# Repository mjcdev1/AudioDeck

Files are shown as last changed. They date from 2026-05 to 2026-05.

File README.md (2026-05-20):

# AudioDeck

## What is an AudioDeck? 
A desktop audio controller for Windows computers - allowing users to modify various sound and microphone settings on the fly without havng to stop what they are doing on their PC. 

## Compatible Component Versions for Latest Product Release
#### To ensure full compatibility, the following component versions should be used when building the latest stable version of the project:

| Component | Version |
|---|---|
| Electronics | Prototype 0.5 |
| Enclosure | Prototype 0.3 |
| Firmware | N/A |
| PC Home App | N/A |

## Important Quick Links

#### Building
| Document | Link |
|---|---|
| Pin Table | [View](docs/references/pin_table.md) |
| Key Matrix Wiring Guide | [View](docs/guides/key_matrix_wiring_guide.md) |
| Component Purchase Guide | [View](docs/guides/component_purchase_guide.md) |

#### Development
| Document | Link |
|---|---|
| Changelog | [View](docs/development/changelog.md) |
| Todo | [View](docs/development/todo.md) |

## Directory Guide
```text
/ *** The directory/ organization setup will likely change often and I will try to keep this guide updated as such
├── docs/                     
│   ├── guides/               # Setup, usage, building, troubleshooting guides 
│   ├── references/           # Datasheets, pinouts, protocols, layouts, wiring schematics (image) 
│   └── development/          # Changelog, todo, design notes
├── hardware/                 # Schematics, PCB files, wiring
│   ├── enclosure/            # All CAD files related to enclosure (case) parts
│   └── electronics/          # Wiring Schematics
|       └── PCB/              # PCB gerber files
│
├── software/            
│   ├── firmware/             # RP2040 firmware
│   └── pc-app/               # Desktop host application
│
└── README.md
```

## Plans for the AudioDeck
The AudioDeck will initially be made as a handwired version, with a PCB version eventually being released.
### Planned Features
- Control system audio volume using a slider
- Mute system audio using a key
- Mute/ unmute system microphone using a key
- Assign up to 5 customs macro keys for any purpose
- Next, Previus, Play/ Pause function keys that will control your active media session (youtube, spotify, VLC etc)
- Using the built in menu: 
  - View and modify per app audio volume of all active audio sessions (spotify, discord, chrome etc)
  - Select and update both input and output audio devices
  - Pin your favorite audio apps for quick access
  - Modify AudioDeck settings like screen brightness, encoder sensitivity and more
- Idle screen when not actively using the menu which may display things like the current time and date, and possibly even PC component status (GPU temp, CPU temp and load etc)
- A PC home app that will allow the board to communicate with your PC to allow viewing and mofications of audio sessions and devices
- Using the PC home app, you will have access to further AudioDeck preferences/ settings like:
  - Enabling/ Disabling audio apps you want to be able to see and modify on the AudioDeck
  - Setting up your custom macro keys
  - Potentionally being able to change AudioDeck screen layout/ colors/ design
  - Potentially being able to upload GIFs to be used in the idle menu
  - MORE IDEAS COMING SOON!!!

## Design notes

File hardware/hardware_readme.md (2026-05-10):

# / hardware
This directory will contain all project files pertaining to hardware, such as CAD files for the enclosure and plate, and PCB gerber files.

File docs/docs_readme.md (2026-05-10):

# / docs
This directory will contain project documentation such as guides, pin tables, component lists, and the changelog.

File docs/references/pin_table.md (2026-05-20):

# Pinout Table

> [!NOTE]
> This document provides the pinouts for the latest stable Electronics release version.
>
> Currently, it reflects the pinouts for [Electronics Prototype 0.5](/hardware/Electronics/Prototype%201.1).

> [!IMPORTANT]
> Cherry MX keyswitch pinouts are not included in this document, as they require a row/column matrix setup.
>
> Please refer to the [Key Matrix Wiring Guide](/docs/guides/key_matrix_wiring_guide.md)

> [!NOTE]
> - Unused pins from the schematic are not included in this table.
> - Unless otherwise specified, all GPIO references refer to RP2040 GPIO pins.
> - This document only covers connections from external components.
> - The RP2040 only needs to provide the shared 3V3 and GND rails used throughout the project.
> - Subscript text in the “Pin From” column shows more common pin names, while the main label matches the naming used in the project schematic.

> [!CAUTION]
> - Components purchased from vendors other than those listed in the recommended component purchase guide may have different pin layouts or orientations. As a result, some pinouts in this document may not exactly match your components.
> - For the best results and to help keep this document accurate, please use the components listed in the [Project Component Purchase Guide](/docs/guides/component_purchase_guide.md).

### EC11 Encoder A

| Pin From | Pin To |
| --- | --- |
| **S** <sub>Switch</sub> | GPIO `2` |
| **A** <sub>Out A</sub> | GPIO `3` |
| **B** <sub>Out B</sub> | GPIO `1` |
| **G** <sub>Ground</sub> | GND Rail |

### EC11 Encoder B

| Pin From | Pin To |
| --- | --- |
| **S** <sub>Switch</sub> | GPIO `27` |
| **A** <sub>Out A</sub> | GPIO `29` |
| **B** <sub>Out B</sub> | GPIO `23` |
| **G** <sub>Ground</sub> | GND Rail |

### Slider Potentiometer 10 kΩ

| Pin From | Pin To |
| --- | --- |
| **OTA** | GPIO `28` |
| **VCC** | 3V3 Rail |
| **GND** | GND Rail |

### ON-OFF-ON SPDT Toggle Switch A

| Pin From | Pin To |
| --- | --- |
| **ON_A** | GPIO `5` |
| **ON_B** | GPIO `4` |
| **GND** | GND Rail |

### ON-OFF-ON SPDT Toggle Switch B

| Pin From | Pin To |
| --- | --- |
| **ON_A** | GPIO `7` |
| **ON_B** | GPIO `6` |
| **GND** | GND Rail |

### Piezo Active Buzzer Circuit

> The longer leg of the piezo buzzer is positive, and the shorter leg is negative.

| Pin From | Through | Pin To |
| --- | --- | --- |
| 2N4401 **Base** | 1kΩ resistor | GPIO `2` |
| 2N4401 **Emitter** |  | GND Rail |
| Piezo **Negative** |  | 2N4401 **Collector** |
| Piezo **Positive** |  | 3V3 Rail |
| 1N4007 **Anode** |  | Piezo **Negative** / 2N4401 **Collector** |
| 1N4007 **Cathode** |  | 3V3 Rail |

### WS2812B ARGB LED Chain (8)

| Pin From | Through | Pin To |
| --- | --- | --- |
| LSQ1 **Base** | 1kΩ resistor | GPIO `16` |
| LSQ1 **Emitter** |  | GND Rail |
| LSQ1 **Collector** | 2.2kΩ resistor | 5V Rail |
| LSQ1 **Collector** / 2.2kΩ node | 1kΩ resistor | LSQ2 **Base** |
| LSQ2 **Emitter** |  | GND Rail |
| LSQ2 **Collector** | 2.2kΩ resistor | 5V Rail |
| LSQ2 **Collector** / 2.2kΩ node | 470Ω resistor | LED 1 **DIN** |
| LED 1 **DOUT** |  | LED 2 **DIN** |
| LED 2 **DOUT** |  | LED 3 **DIN** |
| LED 3 **DOUT** |  | LED 4 **DIN** |
| LED 4 **DOUT** |  | LED 5 **DIN** |
| LED 5 **DOUT** |  | LED 6 **DIN** |
| LED 6 **DOUT** |  | LED 7 **DIN** |
| LED 7 **DOUT** |  | LED 8 **DIN** |
| All LED **VDD** pins |  | 5V Rail |
| All LED **GND** pins |  | GND Rail |

### ILI9341 2.4" Display

| Pin From | Pin To |
| --- | --- |
| **LED** | 3V3 Rail |
| **SCK** | GPIO `26` |
| **SDI** <sub>MOSI</sub> | GPIO `22` |
| **DC** | GPIO `21` |
| **RESET** | GPIO `20` |
| **CS** | GPIO `19` |
| **GND** | GND Rail |
| **VCC** | 3V3 Rail |

### Power Filtering / Decoupling

| Pin From | Through | Pin To |
| --- | --- | --- |
| 3V3 Rail | 0.1 µF ceramic capacitor | GND Rail |
| 3V3 Rail | 4.7 µF ceramic capacitor | GND Rail |
| ILI9341 VCC | 0.1 µF ceramic capacitor | ILI9341 GND |
| R3 / 5V rail node | 0.1 µF ceramic capacitor | GND |
| R5 / 5V rail node | 0.1 µF ceramic capacitor | GND |
| LED1 VDD / 5V rail node | 0.1 µF ceramic capacitor | GND |

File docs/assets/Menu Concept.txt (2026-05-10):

Idle Screen
+------------------------------+
| 12:45 PM                     |
| Tue, Apr 28                  |
|                              |
| PC Status: Connected         |
|                              |
|                              |
+------------------------------+

Main Menu
+------------------------------+
| Main Menu                    |
|                              |
| > App Volumes                |
|   System Audio               |
|   Audio Output               |
|   Microphone Input           |
|   Settings                   |
+------------------------------+

App Volumes
+------------------------------+
| App Volumes                  |
|                              |
| > Discord   [########--] 74% |
|   Spotify   [#####-----] 50% |
|   CS2.exe   [##########]100% |
|   Chrome    [###-------] 25% |
|                              |
+------------------------------+

App Control (Spotify)
+------------------------------+
| Spotify                      |
|                              |
| Volume: 50%                  |
| [#####-----]                 |
|                              |
| Pinned: No                   |
|                              |
+------------------------------+

System Audio
+------------------------------+
| System Audio                 |
|                              |
| Volume: 100%                 |
| [##########]                 |
|                              |
| Mic: MUTED                   |
|                              |
+------------------------------+

Audio Output
+------------------------------+
| Audio Output                 |
|                              |
| > Headphones                 |
|   Speakers                   |
|                              |
|                              |
|                              |
+------------------------------+

Microphone Input
+------------------------------+
| Microphone Input             |
|                              |
| > External Mic               |
|   Built-in Mic               |
|                              |
|                              |
|                              |
+------------------------------+

Settings
+------------------------------+
| Settings                     |
|                              |
| > Brightness                 |
|   Screen Timeout             |
|   Knob Sensitivity           |
|   Reset Favorites            |
|                              |
+------------------------------+

Controls
Encoder A (Rotate)   - Navigate menus  
Encoder A (Press)    - Select/ Confirm  
Encoder A (Hold)     - Go Back  

Encoder B (Rotate)   - Adjust per-app volume  
Encoder B (Press)    - Toggle app mute  

Slider               - Master volume (always active)  

Next                 - Next track  
Previous             - Previous track  
Play/ Pause          - Toggle play/pause 

System Mute          - Mute all system audio  
Mic Mute             - Mute microphone  

M1–M5                - User defined macros

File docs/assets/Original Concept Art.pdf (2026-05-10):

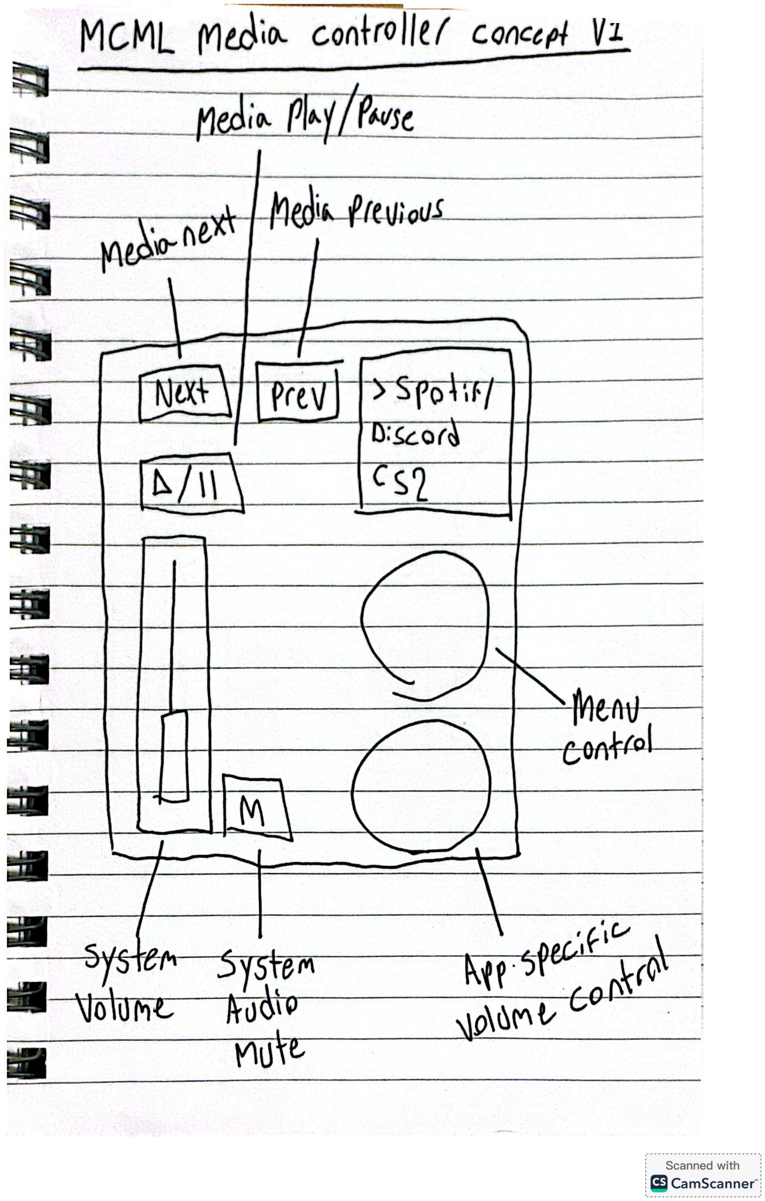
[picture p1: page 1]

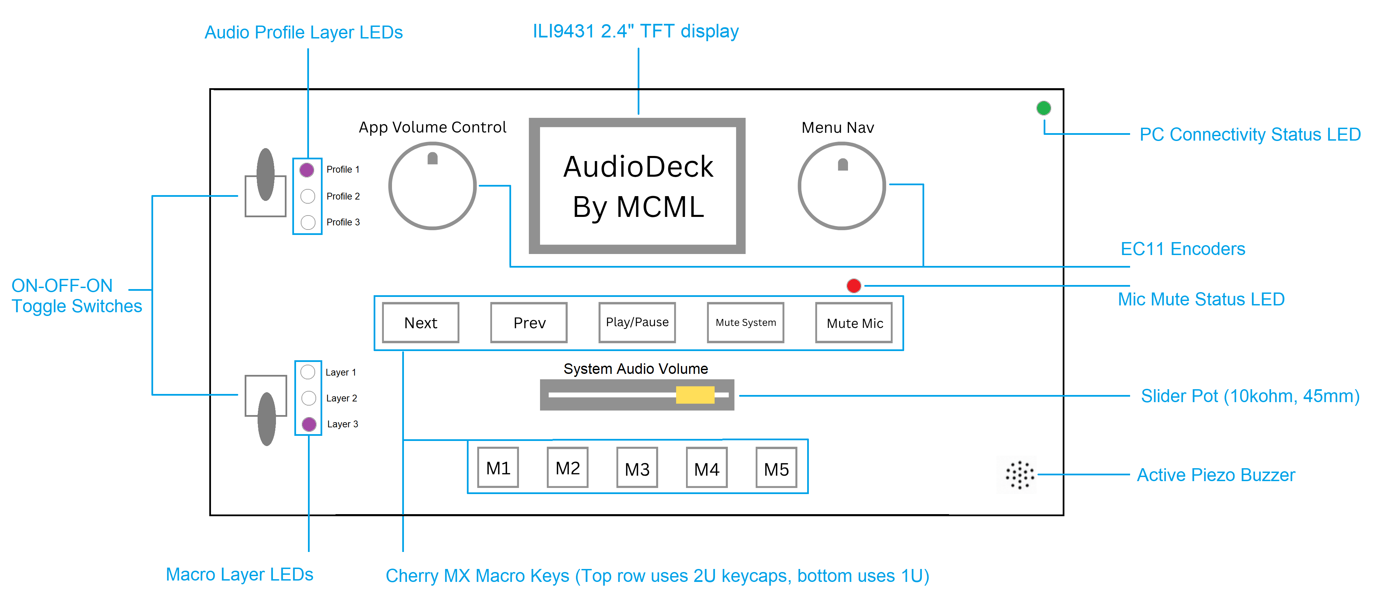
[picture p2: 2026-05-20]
docs/assets/Layout Concept of Prototype 1.4 with Labels.png

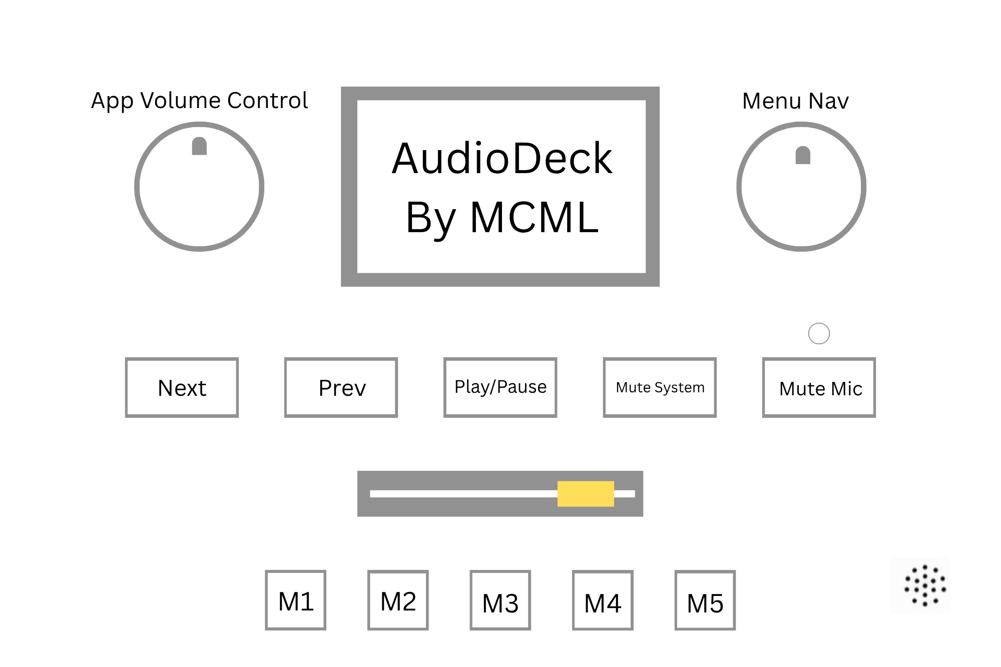
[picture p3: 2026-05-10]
docs/assets/Layout Version 1.png

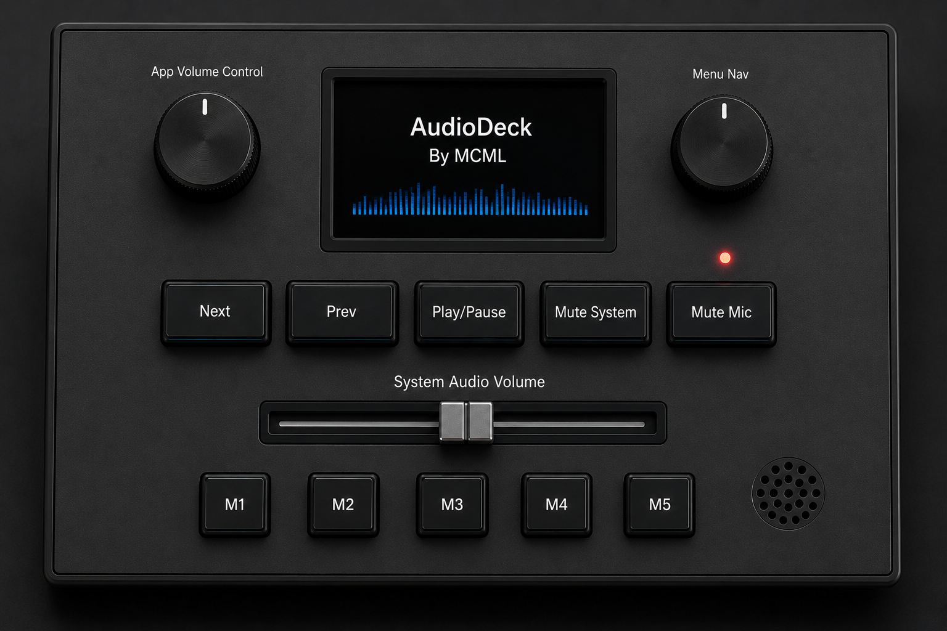
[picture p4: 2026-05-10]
docs/assets/Layout Version 1 render.png

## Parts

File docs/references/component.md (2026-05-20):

# Components

### Reference sheet showing all electronic components used in the latest stable release, along with purchase links and component history across hardware revisions.

> [!NOTE]
> This document acts as a reference sheet for all electronic components used in the latest stable hardware release, along with links to the parts used during development.
>
> It also includes the history of component additions, removals, and replacements across each hardware prototype revision.
>
> Currently, this document reflects the components used in [Electronics Prototype 0.3](/hardware/Electronics/Prototype%201.5).

> [!TIP]
> Components where the **Link** column is marked as `Any` are considered generic enough that they can typically be purchased from any vendor without causing compatibility issues.

---

# Components List

## Main Components

| Component | Quantity | Link |
| --- | --- | --- |
| EC11 Encoder | 2 | TBA |
| Cherry MX Switch | 10 | Any |
| 3-Pin ON-OFF-ON Toggle Switch | 2 | TBA |
| Generic RP2040 Pico | 1 | TBA |
| 2.4" ILI9341 TFT Display | 1 | TBA |
| 5mm WS2812B ARGB LED (Through-Hole) | 8 | TBA |
| Active Piezo Buzzer | 1 | TBA |
| 10kΩ Linear Slider Potentiometer (45mm) | 1 | TBA |

## Support Components

| Component | Quantity | Link |
| --- | --- | --- |
| 1N4148 Diode | 10 | Any |
| 470Ω Resistor | 1 | Any |
| 1kΩ Resistor | 3 | Any |
| 2.2kΩ Resistor | 2 | Any |
| 0.1uF Ceramic Capacitor | 5 | Any |
| 4.7uF Ceramic Capacitor | 1 | Any |
| 1N4007 Diode | 1 | Any |
| 2N4401 Transistor | 3 | Any |

---

# Components History

<details>
<summary><strong>Prototype 0.5</strong></summary>

#### Main Components

- Added
  - `[+]` 3× 5mm WS2812B 4-Pin ARGB LEDs (Through-Hole)
  - `[+]` 1x 3-Pin ON-OFF-ON Toggle Switch

#### Support Components

###### No additions or removals in this revision.

</details>

<details>
<summary><strong>Prototype 0.4</strong></summary>

#### Main Components

- Removed
  - `[-]` 4× 5mm CC 4-Pin Full-Color RGB LEDs (Through-Hole)

- Added
  - `[+]` 5× 5mm WS2812B 4-Pin ARGB LEDs (Through-Hole)

#### Support Components

- Removed
  - `[-]` 5× 470Ω Resistors

- Added
  - `[+]` 2× 2N4401 Transistors
  - `[+]` 2× 1kΩ Resistors
  - `[+]` 2× 2.2kΩ Resistors
  - `[+]` 3× 0.1uF Ceramic Capacitors

</details>

<details>
<summary><strong>Prototype 0.3</strong></summary>
  
#### Main Components

###### No additions or removals in this revision.

#### Support Components

###### No additions or removals in this revision.

</details>

<details>
<summary><strong>Prototype 0.2</strong></summary>

#### Main Components

- Removed
  - `[-]` 1× 5mm Red LED (Through-Hole)

- Added
  - `[+]` 4× 5mm CC 4-Pin Full-Color RGB LEDs (Through-Hole)
  - `[+]` 1× 3-Pin ON-OFF-ON Toggle Switch

#### Support Components

- Added
  - `[+]` 5× 470Ω Resistors
  - `[+]` 1× 1kΩ Resistor
  - `[+]` 1× 1N4007 Diode
  - `[+]` 1× 2N4401 Transistor
  - `[+]` 2× 0.1uF Ceramic Capacitors
  - `[+]` 1× 4.7uF Ceramic Capacitor

</details>

<details>
<summary><strong>Prototype 0.1</strong></summary>

#### Main Components

- Added
  - `[+]` 1× Generic RP2040 Pico
  - `[+]` 2× EC11 Encoders
  - `[+]` 1× 10kΩ Linear Slider Potentiometer (45mm)
  - `[+]` 1× 5mm Red LED (Through-Hole)
  - `[+]` 1× 2.4" ILI9341 TFT Display
  - `[+]` 10× Cherry MX Switches
  - `[+]` 1× Active Piezo Buzzer

#### Support Components

- Added
  - `[+]` 10× 1N4148 Diodes
  - `[+]` 1× 470Ω Resistor

</details>

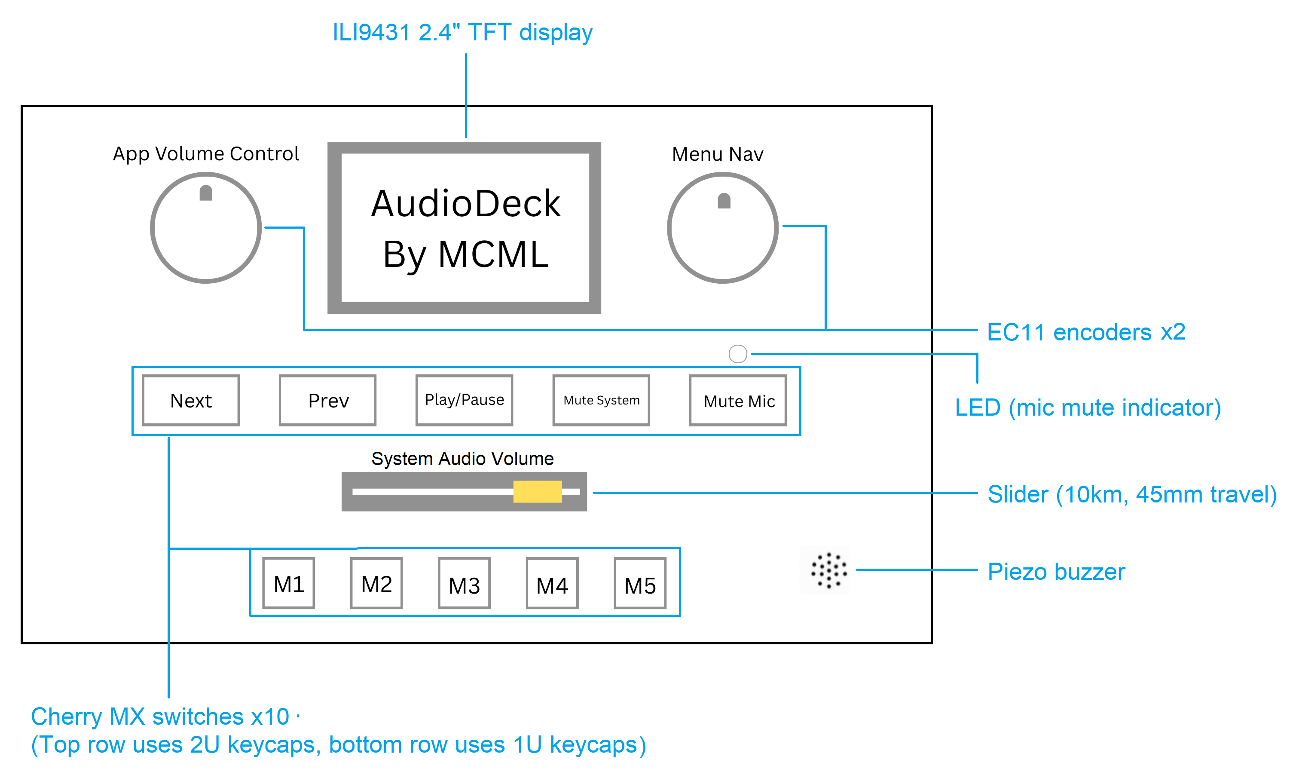
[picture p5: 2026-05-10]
docs/assets/Layout Version 1 with Labeled Components-.png

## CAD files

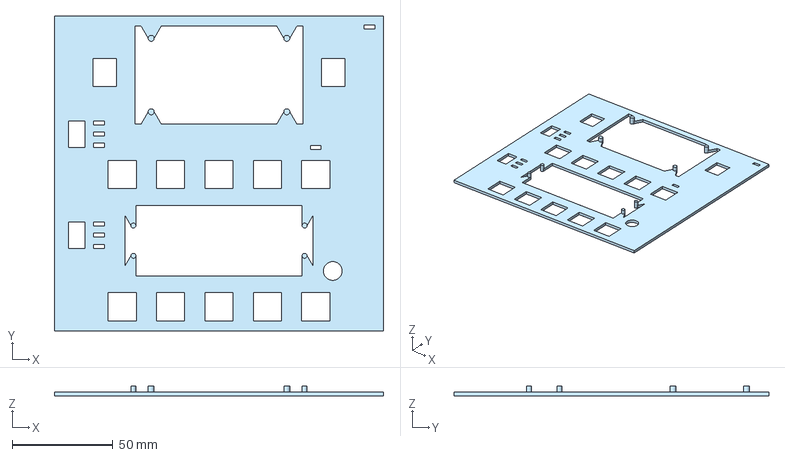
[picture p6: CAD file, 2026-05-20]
hardware/Enclosure/Prototype 0.3/Plate/Prototyping Plate 0.3.step
163.3 x 156.3 x 5.00 mm

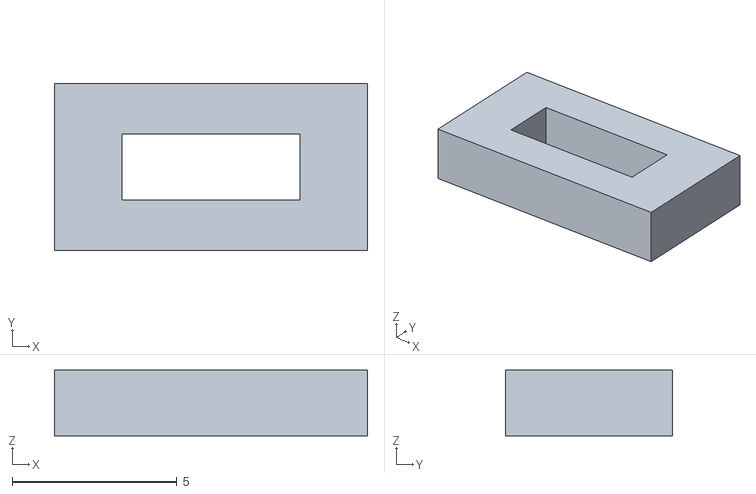
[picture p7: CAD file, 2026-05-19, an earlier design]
hardware/Enclosure/Prototype 0.2/Plate/Slot fit tests/Full-Color LED fit test.stl
9.51 x 5.07 x 2.00

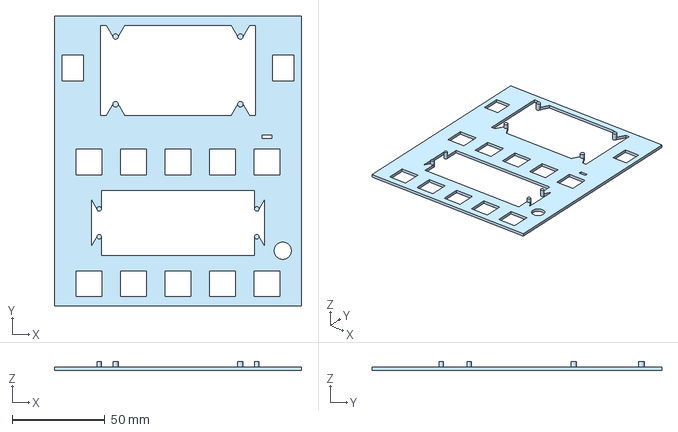
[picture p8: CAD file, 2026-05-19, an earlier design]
hardware/Enclosure/Prototype 0.1/Plate/Prototyping plate.step
133.3 x 156.3 x 5.00 mm

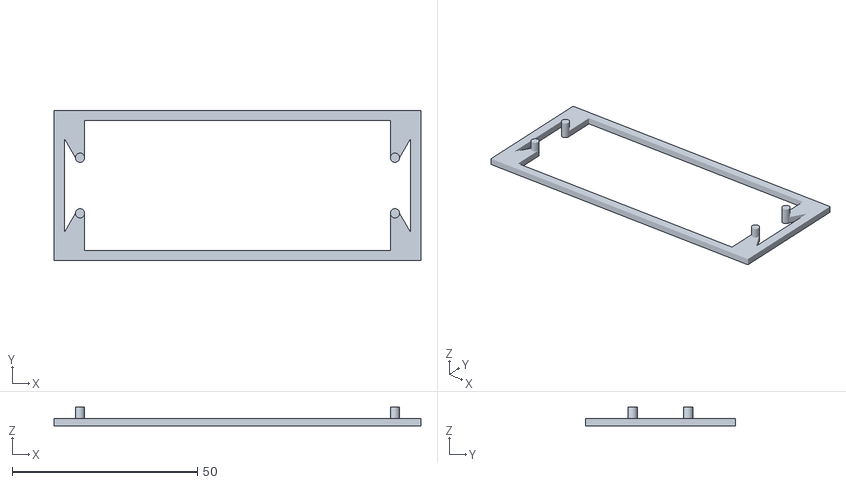
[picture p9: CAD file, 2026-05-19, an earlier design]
hardware/Enclosure/Prototype 0.1/Plate/Slot fit tests/Slider fit test.stl
99.1 x 40.5 x 5.00

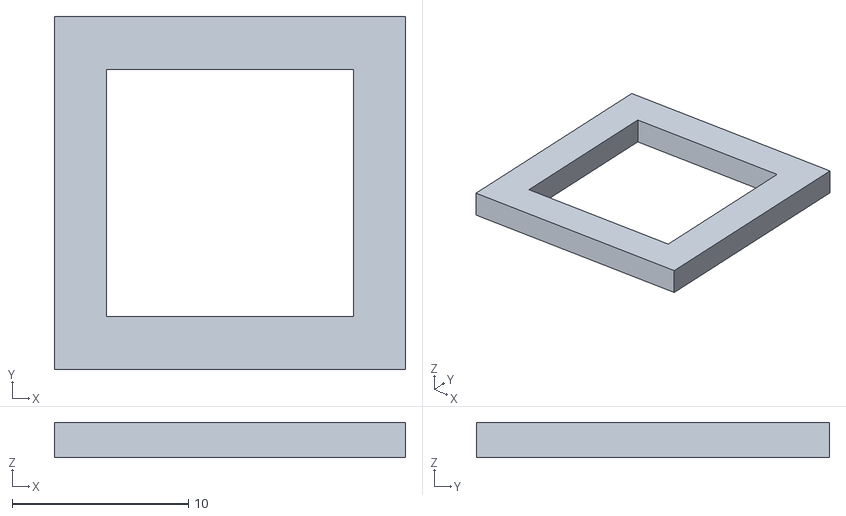
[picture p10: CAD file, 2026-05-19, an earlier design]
hardware/Enclosure/Prototype 0.1/Plate/Slot fit tests/Cherry MX fit test.stl
19.9 x 20.0 x 2.00

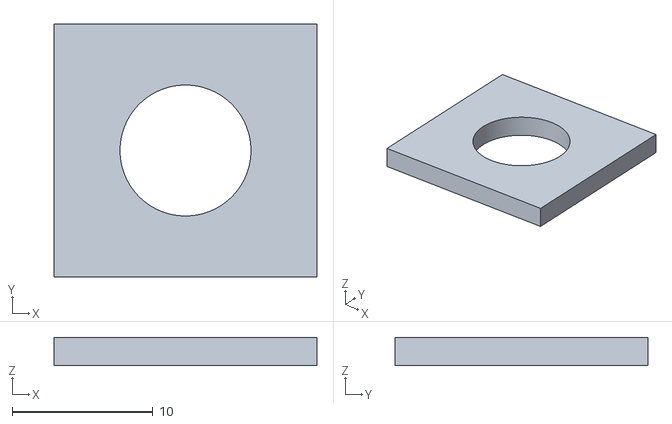
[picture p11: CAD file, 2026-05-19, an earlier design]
hardware/Enclosure/Prototype 0.2/Plate/Slot fit tests/Piezo Buzzer fit test.stl
18.7 x 18.0 x 2.00

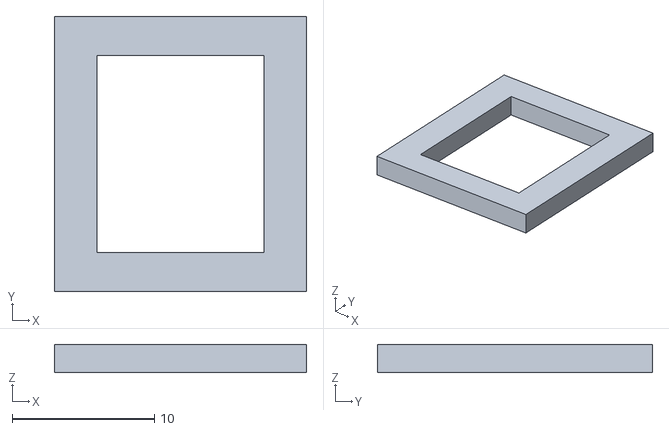
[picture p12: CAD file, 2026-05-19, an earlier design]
hardware/Enclosure/Prototype 0.1/Plate/Slot fit tests/EC11 fit test.stl
17.7 x 19.3 x 2.00

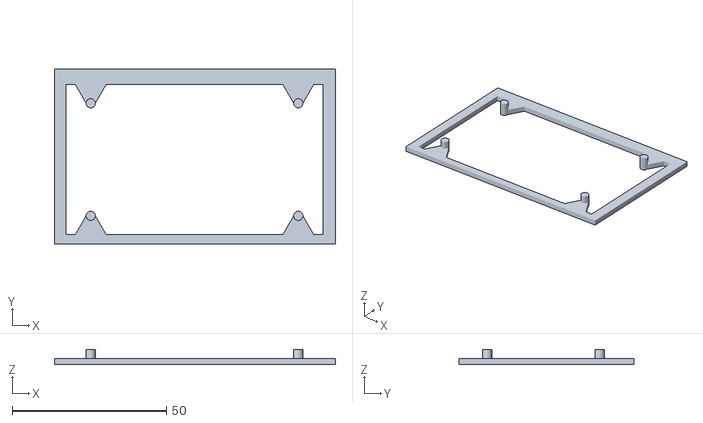
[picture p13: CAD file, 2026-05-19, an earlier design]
hardware/Enclosure/Prototype 0.1/Plate/Slot fit tests/ILI9341 fit test.stl
91.1 x 56.6 x 5.00

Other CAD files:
hardware/Enclosure/Prototype 0.2/Plate/Prototyping Plate 0.2.step
hardware/Enclosure/Prototype 0.1/Plate/Prototyping plate.stl
hardware/Enclosure/Prototype 0.2/Plate/Prototyping Plate 0.2.stl
hardware/Enclosure/Prototype 0.3/Plate/Prototyping Plate 0.3.stl

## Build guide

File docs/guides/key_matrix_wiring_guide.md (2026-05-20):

# Key Matrix Wiring Guide

### Matrix Configuration

This project uses a **COL2ROW** key matrix configuration for the 10 Cherry MX key switches. 

In this arrangement:
- Columns connect directly to one side of each keyswitch
- The opposite switch pin connects to the anode of the diode
- The cathode of the diode connects to the row wire
  > Note: You can determine the cathode side of a 1N4148 by the end with the black stripe

You will repeat this process for each key to form the columns and rows. 

This table shows the connections for a single key: 
| Connection | Connects To |
|---|---|
| Column Wire | Switch Pin 1 |
| Switch Pin 2 | Diode Anode |
| Diode Cathode (black stripe) | Row Wire |

### Matrix current path:

```text
Column → Switch → Diode → Row
```

### Diode Orientation

| Diode Side | Connection |
|---|---|
| Anode | Switch Pin 2 |
| Cathode | Row Wire |

> [!WARNING]
> All matrix diodes **have** to face the exact same direction
>
> Reversed diode orientation may prevent proper matrix scanning or cause ghosting issues.

---

### Matrix GPIO Pinout

With the rows and columns formed, you can directly connect them (from anywhere on the wires) to the below GPIO pins: 

| Matrix Reference | GPIO Pin |
|---|---|
| COL1 | GPIO `11` |
| COL2 | GPIO `12` |
| COL3 | GPIO `13` |
| COL4 | GPIO `14` |
| COL5 | GPIO `15` |
| ROW1 | GPIO `10` |
| ROW2 | GPIO `9` |

---

> [!NOTE]
> Cherry MX switches are not polarized, therefore you can orient the switch any way you want as long as one pin follows the columns and the other follows the rows.

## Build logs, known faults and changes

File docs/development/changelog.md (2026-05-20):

<!--
COLLAPSIBLE CHANGELOG ENTRY TEMPLATE

<details>
<summary><strong>Prototype X.X — YYYY/MM/DD</strong></summary>

- Main change
  - Sub change
  - Sub change

- Another main change
  - Sub change

</details>

-->

# Changelog!

## 🔌 HARDWARE — Prototype 0.3

### ENCLOSURE

<details>
<summary><strong>Prototype 0.3</strong></summary>

#### 2026/05/19
- Added four additional LED slots
- Added slot for a second ON-OFF-ON SPDT toggle

</details>

<details>
<summary><strong>Prototype 0.2</strong></summary>

#### 2026/05/12
- Added three additional LED slots
- Added slot for an ON-OFF-ON SPDT toggle switch
- Tested fitment of all component cutouts using 3D printed test pieces
  - Adjusted EC11 cutouts for improved fitment

</details>

<details>
<summary><strong>Prototype 0.1</strong></summary>

#### 2026/05/10
- Designed initial prototyping plate with mounts and cutouts for all planned components
  - Created individual fit-test cutouts before printing the full plate

</details>

### ELECTRONICS

<details>
<summary><strong>Prototype 0.5 </strong></summary>

#### 2026/05/19

- Added three more WS2812B ARGB LEDs
  - Intended to indicate the current macro layer
- Added another 3-pin ON-OFF-ON toggle switch (Referred to as Toggle Switch B)
  - Will allow the user to switch between three macro layers
- Rearranged some pin placements, specifically affecting the key matrix, EC11-A and Toggle Switch A.
- Updated pinout reference to reflect changes

</details>

<details>
<summary><strong>Prototype 0.4 </strong></summary>

#### 2026/05/18

- Added 5V rail net from VOUT on RP2040
- Created and added a custom schematic symbol for WS2812B ARGB LEDs (through-hole, individual)
- Replaced all common cathode 4-pin RGB LEDs with WS2812B ARGB LEDs
- Added support circuitry for addressable LED communication
- Added double-transistor level shifter for 3.3V to 5V data conversion
- Added additional (5th) ARGB LED

</details>

<details>
<summary><strong>Prototype 0.3 </strong></summary>

#### 2026/05/13
- Completely rewired the 10-key matrix
- Converted matrix wiring to a COL2ROW configuration
- Corrected previous matrix routing issues to ensure proper electrical functionality

</details>

<details>
<summary><strong>Prototype 0.2</strong></summary>

#### 2026/05/12

- Changed MIC MUTE LED to a 4-pin common cathode RGB LED
- Added three additional RGB LEDs
  - Intended to indicate active macro layers or custom audio profiles
- Created and added a custom schematic symbol for a 3-pin ON-OFF-ON SPDT toggle switch
  - Intended for macro layer and audio profile selection
- Rearranged several GPIO assignments
  - Primarily affecting EC11 (B) and the piezo buzzer
- Redesigned the piezo buzzer circuit
  - Added transistor driver and flyback diode protection
- Added additional decoupling capacitors throughout the circuit

</details>

<details>
<summary><strong>Prototype 0.1</strong></summary>

#### 2026/05/10

- Designed the initial wiring schematic
- Created custom symbols for unsupported components
  - RP2040
  - ILI9341
- Added shared VCC and GND nets
- Connected all primary external components to the RP2040

</details>

## 💻 SOFTWARE — v0.0.0

### FIRMWARE — v0.0.0

No changes yet.

### PC APP — v0.0.0

No changes yet.

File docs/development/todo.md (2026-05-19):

# Todo!

## Todo in Hardware...
  - [ ] Build simple prototype on breadboard
    - [ ] Design prototyping plate
  - [ ] Change schematic to use 4 pin (4 color) LED instead of single color

## Todo in Software...

## Todo in Documentation/ Assets/ Organization...
  - [X] Reorganize directories per updated organization design... 
    - [X] Move /assets into /docs [ ]
    - [X] Create /docs/guides, /docs/references, and /docs/development 
    - [X] Move changelog.md, changelog_rules.md and todo.md into /docs/development [ ]
    - [X] Create /software and move /firmware and /pc-app into it [ ]

 - [X] Create pinout table
 - [ ] Create key switch matrix wiring guide

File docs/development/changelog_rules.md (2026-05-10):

# Changelog Rules and Conventions

### Semantic Versioning
- Semantic versioning uses the format:
  - vMAJOR.MINOR.PATCH
  - Example:
    - v1.4.2
- Semantic version updates should use the following format:
  - vX.X.X ([CHANGE TYPE]) — [DATE YYYY/MM/DD]
  - Example:
    - v1.3.4 (PATCH) — 2026/04/19
- MAJOR versions represent large redesigns, rewrites, or breaking changes.
- MINOR versions represent new features, systems, or meaningful improvements.
- PATCH versions represent smaller fixes, tweaks, refinements, or corrections.

### Hardware Revision Versioning
- Hardware revision versioning uses the format:
  - Rev A1, Rev A2, Rev B1, Rev B2, etc.
- Hardware revision updates should use the following format:
  - Rev A2 ([CHANGE TYPE]) — [DATE YYYY/MM/DD]
  - Example:
    - Rev B3 (MINOR) — 2026/04/19
- Increment the revision number for smaller revisions or improvements.
- Increment the revision letter for major redesigns or new hardware generations.

### Project Versioning
- Project versions use the format:
  - PROJECT — VX
  - Example:
    - PROJECT — V3
- Project version updates should use the following format:
  - PROJECT — VX — [DATE YYYY/MM/DD]
  - Example:
    - PROJECT — V3 — 2026/04/19
- Project versions represent the overall milestone and progression state of the project as a whole.
- A new Project version should only be created when the project has reached a meaningful new milestone, stage, or release state.

### Project Structure
- The Project is made up of the following categories:
  - Hardware
    - Enclosure
    - Electronics
  - Software
    - Firmware
    - PC Companion App
  - Documentation and Assets

### Hardware Revision Progression
- Hardware uses Hardware Revision Versioning.
- Hardware revisions are determined by the combined progression of the Enclosure and PCB categories.
- A Hardware revision should only increment once both Enclosure and PCB have reached or exceeded the intended revision milestone.
  - Example:
    - Hardware should only reach Rev A2 once both Enclosure and PCB have reached at least Rev A2 or greater.

### Software Version Progression
- Software uses Semantic Versioning.
- Software versions are determined by the combined progression of Firmware and the PC Companion App.
- A Software version should only increment once both Firmware and the PC Companion App have reached or exceeded the intended semantic version milestone.
  - Example:
    - Software should only reach v0.3.0 once both Firmware and the PC Companion App have reached at least v0.3.0 or greater.

### Documentation and Assets Versioning
- Documentation and Assets use Hardware Revision Versioning.
- Documentation and Assets revisions should reflect the overall progression of documentation, organization, and asset-related changes within the category.

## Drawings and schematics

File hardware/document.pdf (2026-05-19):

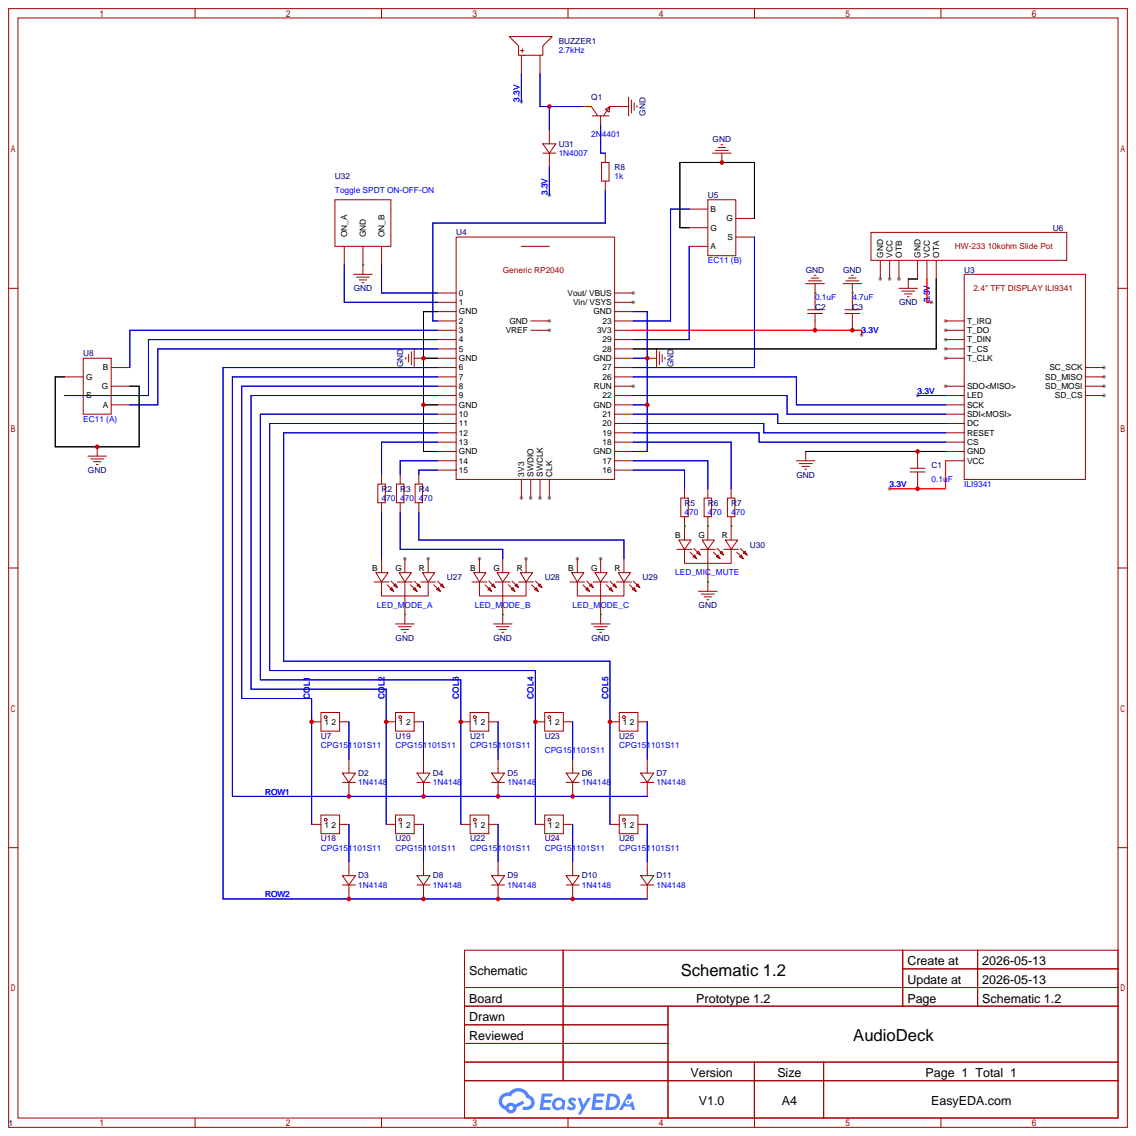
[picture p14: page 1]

Toggle SPDT ON-OFF-ON

Schematic | Schematic 1.2 | Create at | 2026-05-13

Update at | 2026-05-13

Board | Prototype 1.2 | Page | Schematic 1.2
Drawn | | AudioDeck
Reviewed

Version | Size | Page 1 Total 1
V1.0 | A4 | EasyEDA.com

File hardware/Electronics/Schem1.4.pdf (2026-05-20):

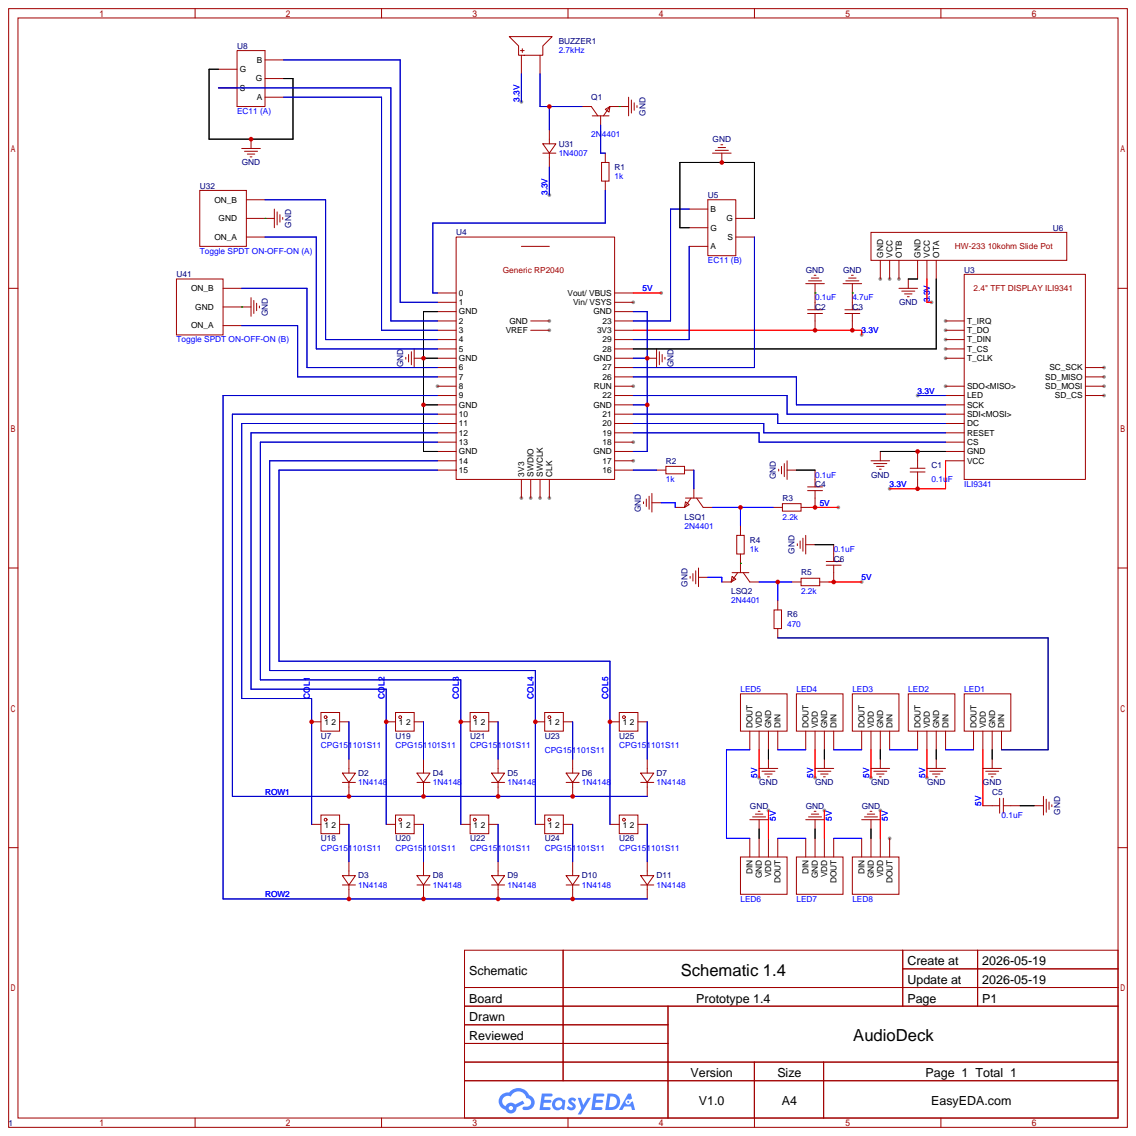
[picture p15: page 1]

Schematic | Schematic 1.4 | Create at | 2026-05-19

Update at | 2026-05-19

Board | Prototype 1.4 | Page | P1
Drawn | | AudioDeck
Reviewed

Version | Size | Page 1 Total 1
V1.0 | A4 | EasyEDA.com

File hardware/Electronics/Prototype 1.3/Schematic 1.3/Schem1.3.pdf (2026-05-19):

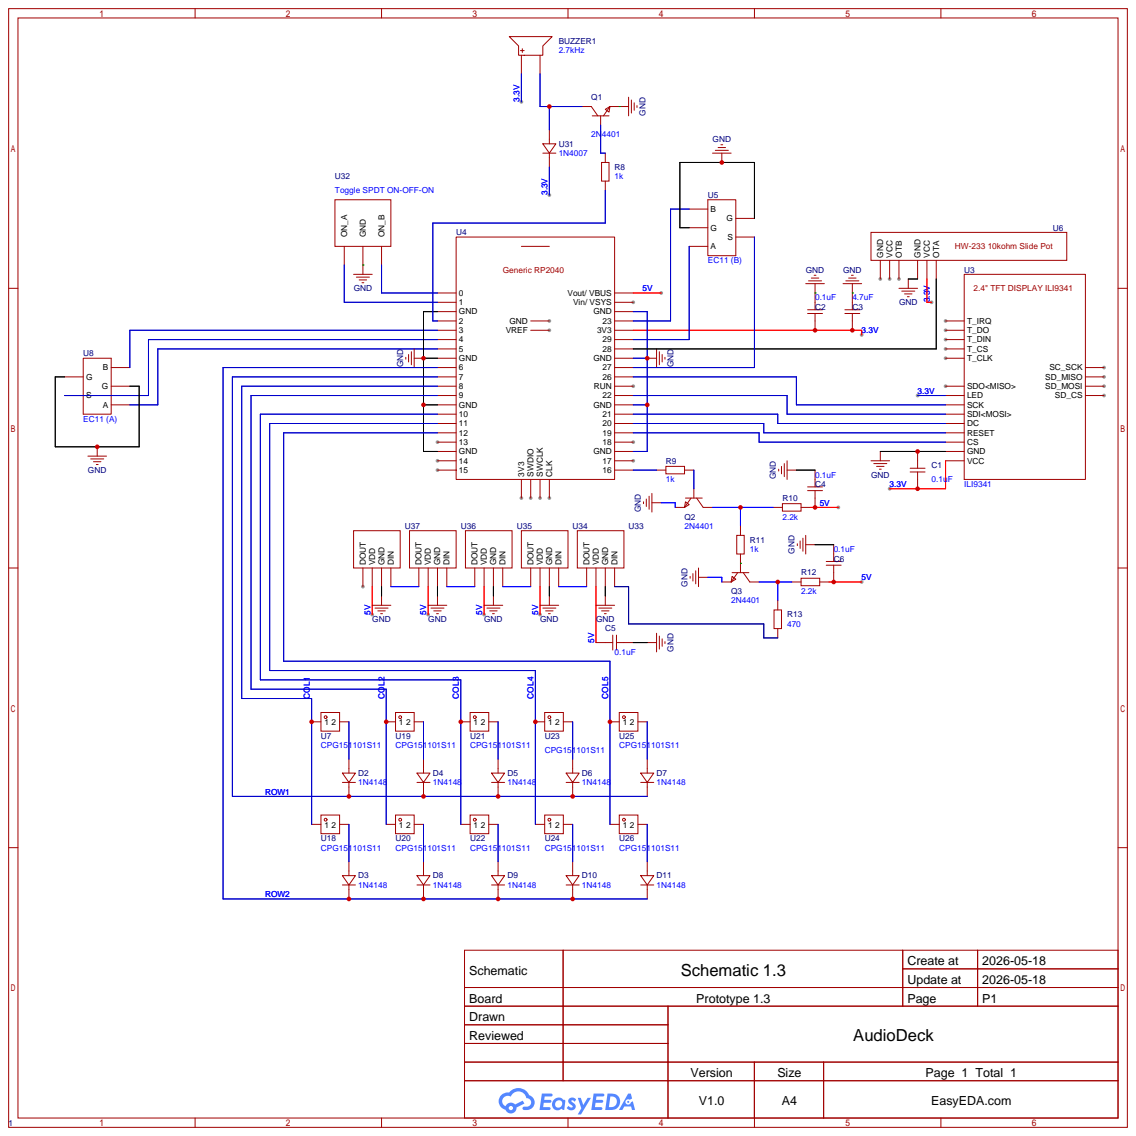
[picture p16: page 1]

Toggle SPDT ON-OFF-ON

Schematic | Schematic 1.3 | Create at | 2026-05-18

Update at | 2026-05-18

Board | Prototype 1.3 | Page | P1
Drawn | | AudioDeck
Reviewed

Version | Size | Page 1 Total 1
V1.0 | A4 | EasyEDA.com

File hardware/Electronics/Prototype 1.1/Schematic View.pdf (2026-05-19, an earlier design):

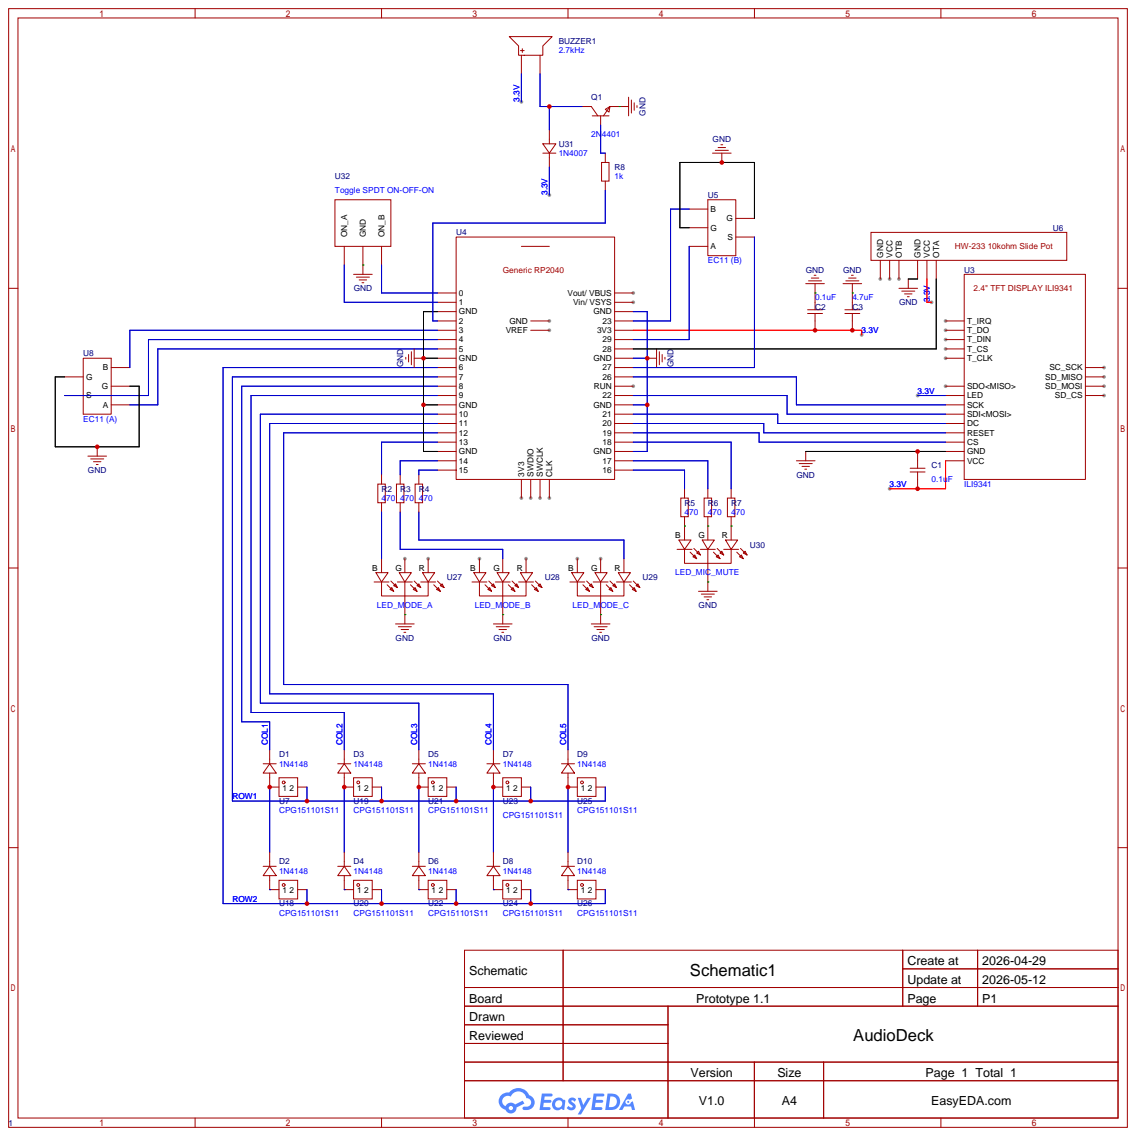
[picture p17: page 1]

Toggle SPDT ON-OFF-ON

Schematic | Schematic1 | Create at | 2026-04-29

Update at | 2026-05-12

Board | Prototype 1.1 | Page | P1
Drawn | | AudioDeck
Reviewed

Version | Size | Page 1 Total 1
V1.0 | A4 | EasyEDA.com

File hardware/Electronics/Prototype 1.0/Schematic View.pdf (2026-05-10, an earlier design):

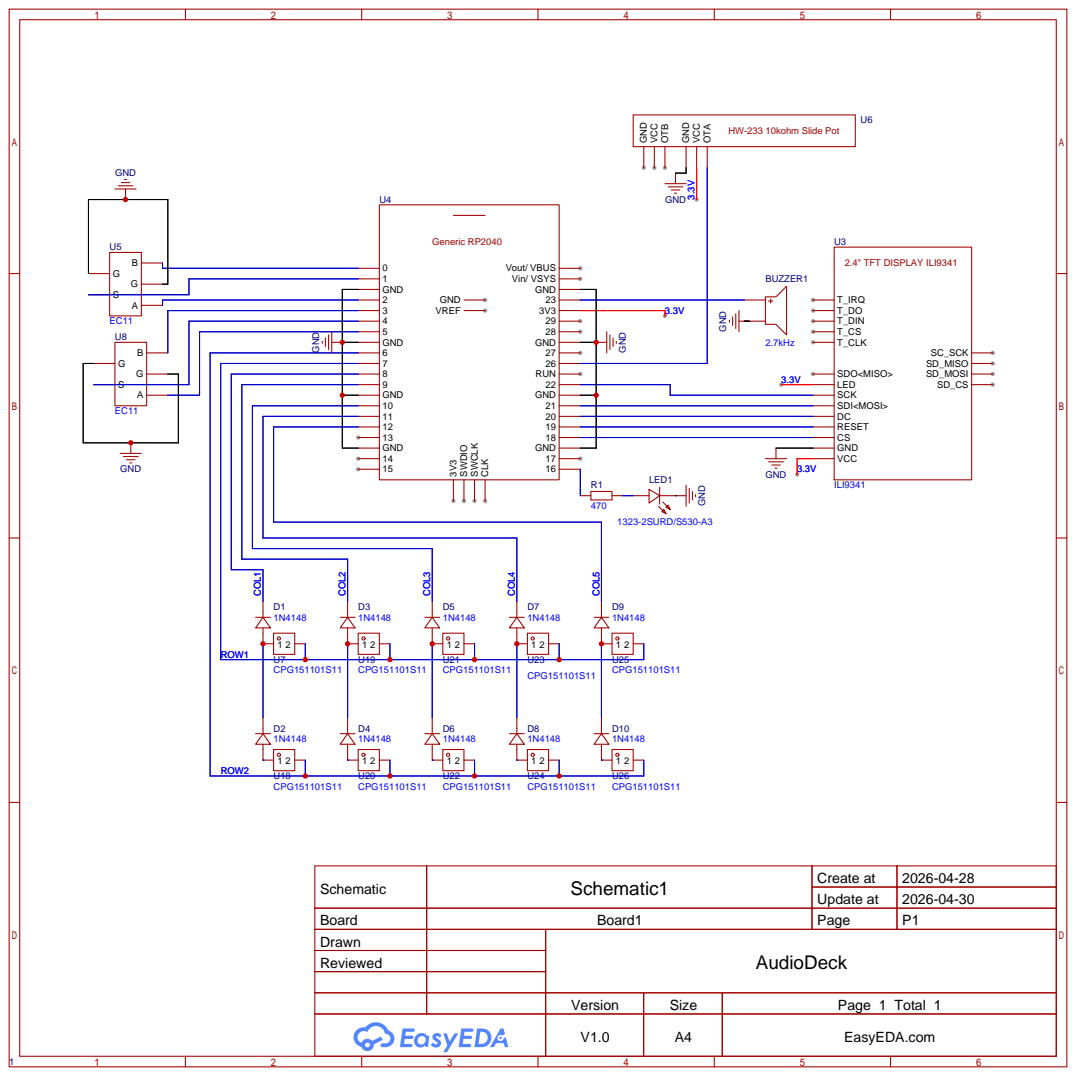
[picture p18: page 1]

Schematic | Schematic1 | Create at | 2026-04-28

Update at | 2026-04-30

Board | Board1 | Page | P1
Drawn | | AudioDeck
Reviewed

Version | Size | Page 1 Total 1
V1.0 | A4 | EasyEDA.com

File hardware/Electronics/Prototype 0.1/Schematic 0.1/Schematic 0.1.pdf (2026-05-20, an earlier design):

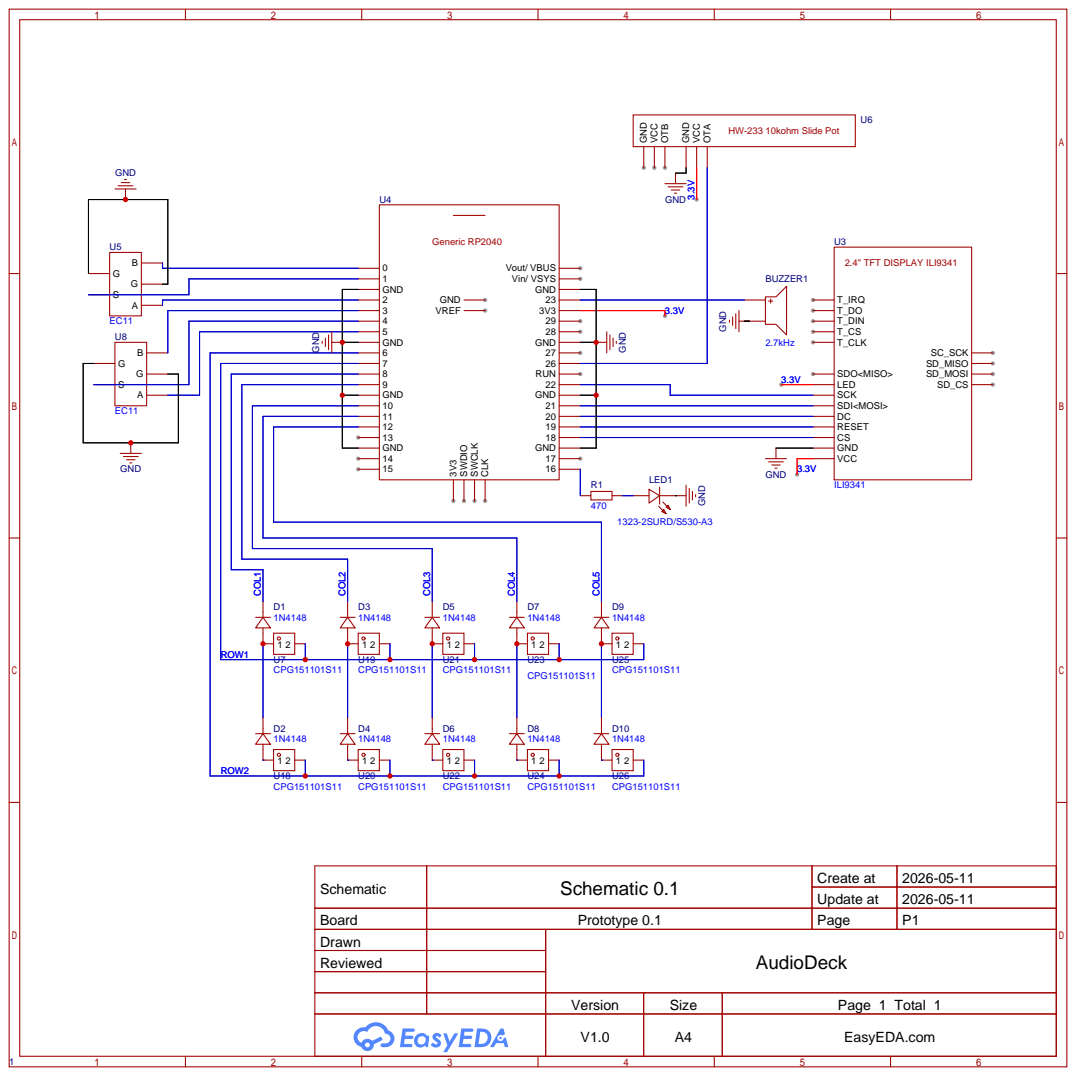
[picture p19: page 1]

Schematic | Schematic 0.1 | Create at | 2026-05-11

Update at | 2026-05-11

Board | Prototype 0.1 | Page | P1
Drawn | | AudioDeck
Reviewed

Version | Size | Page 1 Total 1
V1.0 | A4 | EasyEDA.com

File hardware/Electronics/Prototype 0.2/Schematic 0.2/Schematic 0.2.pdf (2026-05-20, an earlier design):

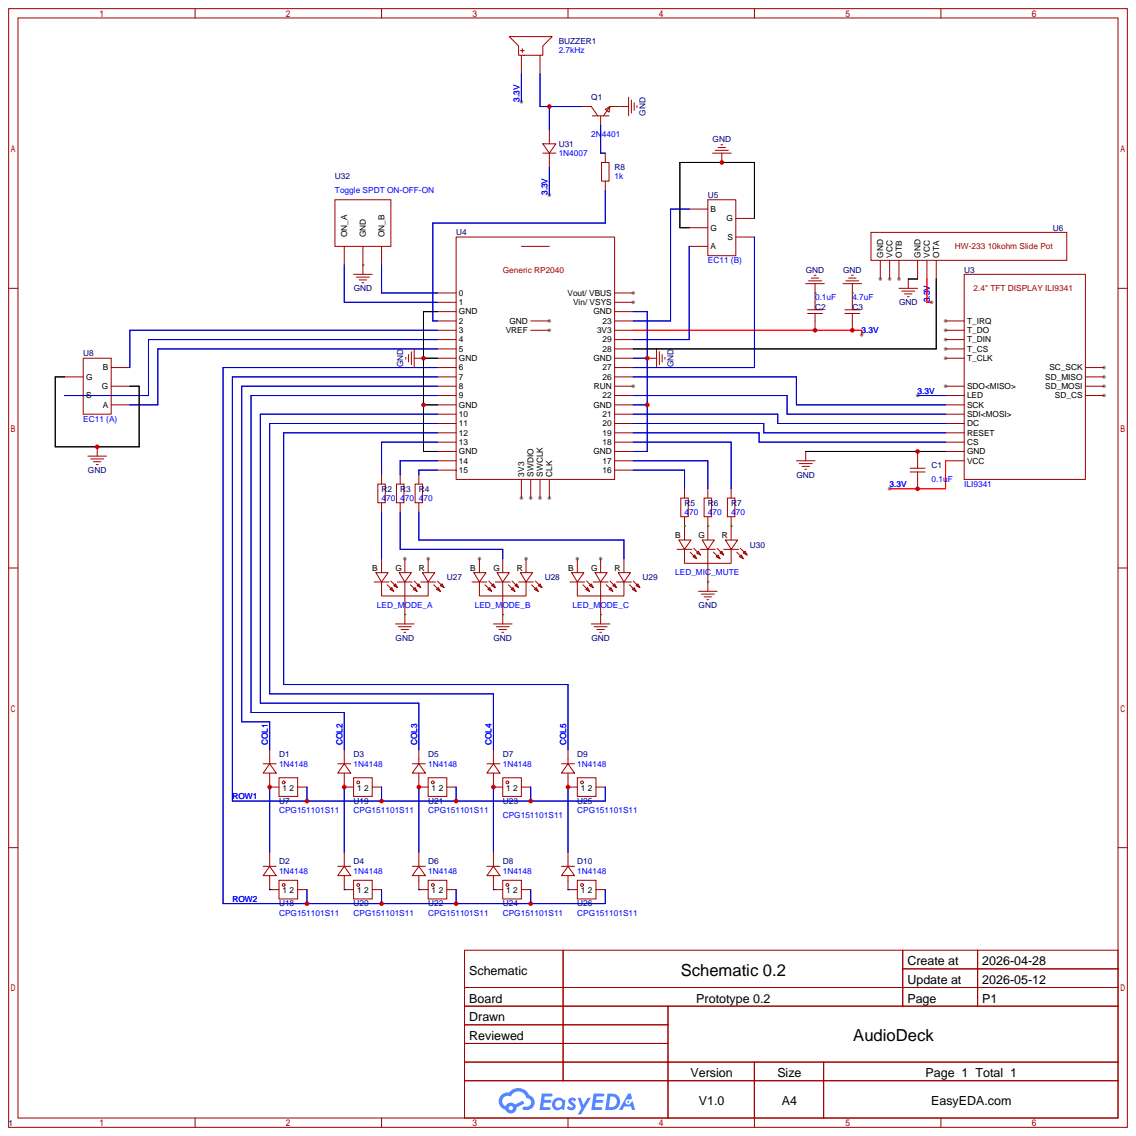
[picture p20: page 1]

Toggle SPDT ON-OFF-ON

Schematic | Schematic 0.2 | Create at | 2026-04-28

Update at | 2026-05-12

Board | Prototype 0.2 | Page | P1
Drawn | | AudioDeck
Reviewed

Version | Size | Page 1 Total 1
V1.0 | A4 | EasyEDA.com

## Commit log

2026-05-10 Squashed all commits into initial setup commit
    [1_P1.schdoc, PCB1.pcbdoc]
2026-05-19 Added Enclosure Prototype A1, updated changelog
    [1_P1.schdoc, Cherry MX fit test.stl, EC11 fit test.stl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]
2026-05-19 Added Prototype 1.1 for both electronics and enclosure. Also, updated pinout reference sheet to match prototype 1.1 schematic.
    [Cherry MX fit test.stl, EC11 fit test.stl, Full-Color LED fit test.stl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]
2026-05-19 Added Prototype Schematic 1.3, also reorganized some files
    [1_P1.schdoc, PCB1.pcbdoc]
2026-05-20 Small fixes and cleanup
    Create component.md
    Update component.md
    Update component.md
    Update component.md
    Update component.md
    Update changelog.md
    Update component.md
    Update component.md
    Update component.md
    Update component.md
    Update component.md
    Update changelog.md
    Update pin_table.md
    Update changelog.md
    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
    [1_P1.schdoc, Prototyping Plate 1.2.step, Prototyping Plate 1.2.stl]
2026-05-20 Added Electronics Prototype 0.5, Enclosure Prototype 0.3, updated layout concept based on Electronics Prototype 0.5. Also did various housekeeping
    [1_P1.schdoc, Cherry MX fit test.stl, EC11 fit test.stl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]
